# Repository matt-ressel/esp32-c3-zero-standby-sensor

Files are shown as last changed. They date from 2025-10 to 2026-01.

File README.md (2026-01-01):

# ESP32-C3 Zero-Standby Environmental Sensor

## 🎯 Project Goal

To create a wireless, battery-powered environmental sensor, optimized for extremely low power consumption. The primary goal is to achieve a theoretical battery life exceeding **10 years** on a single Li-SOCl₂ (e.g., FANSO ER18505M 3.6V, 3500mAh) battery.

This project achieves this goal through a unique **"Zero Standby"** architecture, where the microcontroller is completely disconnected from power during its idle state. The duty cycle is managed by an external, nano-power system timer.

---

## 🚀 Key Features & Architecture

*   **Ultra-Low Electronic Quiescent Current:** The total current consumed by the electronics in the power-off state has been meticulously optimized to be under 100 nA. This value is the sum of the quiescent currents (Iq) of all components permanently connected to the battery:
    *   **TPS63900 Buck-Boost (in shutdown):** ~60 nA
    *   **TPL5111 System Timer:** ~35 nA
    *   **SiP32431 Load Switch (in off-state):** ~0.01 nA (practically zero)
    *   **Total Electronic Iq ≈ 95 nA**

    This successfully achieves the design goal of making the electronic footprint in the standby state almost immeasurable. It ensures that the theoretical battery life is maximized, being limited almost exclusively by the energy consumed during the brief active cycles.
*   **Power Gating Architecture:** Instead of using Deep Sleep mode, the TPL5111 completely enables and disables the power supply for the entire system (MCU + sensor), eliminating any MCU-related leakage currents.
*   **Ultra-Fast On-Time:** The entire active cycle (boot, measure, transmit, shutdown) is highly optimized to complete in **well under 100 milliseconds** (typically ~80ms), which is critical for minimizing energy consumption.
*   **Optimized Operational Sequence:** The firmware uses advanced techniques like **latency hiding**, where long physical processes (like battery measurement stabilization) are executed in the background during other necessary initializations (like the Wi-Fi stack), effectively reducing their time cost to zero.
*   **ESP-NOW Communication:** Utilizes the lightweight and fast ESP-NOW protocol, configured for Long Range (LR) mode, for robust and low-power data transmission.
*   **Professional Component-Based Architecture:** The code is structured into fully independent, reusable components (e.g., `bme280_driver`, `espnow_sender`, `sensor_manager`) in line with the best practices for ESP-IDF, ensuring clean separation of concerns and easy maintenance.

---

## 🛠️ Hardware Components (Bill of Materials)

| Component | Model/Value | Role |
| --- | --- | --- |
| **Microcontroller** | Espressif ESP32-C3-MINI-1 | Main processing unit, RF communication |
| **System Timer** | Texas Instruments TPL5111 | External watchdog and duty cycle manager (Power Gating)  |
| **Buck-Boost Converter**| Texas Instruments TPS63900 | High-efficiency 3.3V voltage regulation |
| **Environmental Sensor**| Bosch BME280 | Measures temperature, humidity, and pressure (I²C) |
| **Battery** | FANSO ER18505M (Li-SOCl₂, 3.6V, 3500mAh) or similar | Primary power source |
| **Load Switch** | Vishay SiP32431 | Switched voltage divider for V_BATT measurement |

---

## 🔄 Optimized Software Operational Sequence

The duty cycle is fast, repeatable, and designed for maximum efficiency. The order of operations is critical.

1.  **START (Cold Boot):** The TPL5111 activates the power converter, supplying power to the system. `app_main` begins execution.

2.  **IMMEDIATE CRITICAL ACTIONS:**
    *   **Initialize Critical Drivers:** The bare minimum of drivers needed for immediate measurements are initialized (`bme280_driver`, `battery_monitor`, `power_manager`).
    *   **Start Battery Measurement:** The firmware immediately enables the external voltage divider. This starts the ~25ms physical process of charging the filter capacitor. This process now runs **in the background**.
    *   **Perform BME280 Measurement:** With the battery measurement stabilizing in the background, the CPU **immediately** performs the BME280 sensor reading. This is done as early as possible to get a temperature reading before the CPU core begins to self-heat.

3.  **LATENCY HIDING & NETWORK INIT:**
    *   While the battery measurement capacitor is charging, the firmware productively uses this time to initialize the time-consuming network stack (`wifi_service` and `espnow_sender`). This **hides the 25ms delay**, effectively making the battery stabilization time "free".

4.  **FINALIZE & TRANSMIT:**
    *   Control is passed to the `sensor_manager`.
    *   It **finalizes the battery measurement** by reading the now-stable voltage from the ADC.
    *   It assembles all data (BME280, battery) into a payload, calculates a CRC, and hands it to the `espnow_sender`.
    *   The `espnow_sender` transmits the packet and waits for a hardware-level acknowledgement (ACK) from the receiver.

5.  **SHUTDOWN:**
    *   Upon completion of the transmission (successful or not), a HIGH pulse is generated on the `DONE` pin.
    *   The TPL5111 receives the signal and immediately cuts off power to the system.
    *   A **fail-safe mechanism** is in place: if the shutdown signal fails, the MCU enters its deepest possible sleep state to conserve energy until the TPL5111's own watchdog timer performs a hard power cycle.

---

## ⚙️ Getting Started & Configuration

This project is designed for rapid setup using the provided configuration files, while still requiring user-specific network details.

### 1. Mandatory User Configuration (menuconfig)

This repository includes a pre-configured `sdkconfig` file containing all the performance optimizations listed below. This saves you the time of setting them manually.

**However, you MUST configure your own network-specific parameters before building and flashing.**

To do this, run `idf.py menuconfig` and navigate to the following menu:

`---> ESP32C3 Zero Standby Sensor Configuration`

Inside this menu, you must set the following values to match your receiver/gateway:

*   **`Gateway MAC Address`**: The MAC address of your ESP-NOW receiver.
*   **`ESPNOW primary master key (PMK)`**: A 16-character string shared with the receiver.
*   **`ESPNOW local master key (LMK)`**: A 16-character string shared with the receiver for this specific device.
*   **`ESPNOW Channel`**: The Wi-Fi channel (1-13) on which both devices will communicate.
*   **`I2C Pin Configuration`**: Specify the GPIO pins used by the I2C master for the BME280.

### 2. Summary of Key Performance Optimizations

For reference, here is a detailed list of the critical optimizations applied in the provided `sdkconfig` to achieve an ultra-fast boot time (cold boot to shutdown in < 100ms).

The following options, configured via `idf.py menuconfig`, are essential for minimizing boot time and runtime power consumption.

#### Compiler Optimization
For maximum performance, both the main application and the bootloader should be compiled with `-O2` optimization.
*   **Application Optimization Level:**
    *   `Compiler options ---> Optimization Level ---> Optimize for performance (-O2)`

*   **Bootloader Optimization Level:**
    *   `Bootloader config ---> Bootloader optimization level ---> Optimize for performance (-O2)`

#### Bootloader & Logging & System
*   **Disable Console Output (CRITICAL):** Disables the UART console driver entirely. This removes the initialization overhead of the UART peripheral and converts all logging macros to no-ops, significantly speeding up boot and execution.
    *   `Component config ---> ESP System Settings ---> Channel for console output (None)`

*   **Skip Image Validation:** This is a major optimization. It instructs the bootloader to skip the time-consuming SHA-256 validation of the application image on every boot.
    *   `Bootloader config ---> [*] Skip image validation always`

*   **Disable Bootloader Log:** Drastically speeds up the initial boot phase.
    *   `Bootloader config ---> Log ---> Bootloader log verbosity ---> No output`

*   **Disable Application Log:** Frees up CPU cycles and reduces on-time. Set to "Info" for debugging and "None" for production.
    *   `Component config ---> Log ---> Log Level ---> Default log verbosity ---> No output`

*   **FreeRTOS:** The project is configured for a single core and a 1000Hz tick rate.
    *   `Component config ---> FreeRTOS ---> Kernel ---> configTICK_RATE_HZ (1000)`

#### ADC & RTC Optimizations
*   **Place ADC ISR in IRAM:** Improves performance of ADC reads by running the code from faster RAM instead of flash.
    *   `Component config ---> ADC ---> [*] Place ISR version ADC oneshot mode read function into IRAM`

*   **Skip RTC Clock Calibration:** Reduces boot time by skipping a time-consuming calibration step.
    *   `Component config ---> Hardware Settings ---> RTC Clock Config ---> (0) Number of cycles for RTC_SLOW_CLK calibration`    

#### Wi-Fi, PHY & LWIP Stack Reduction
The goal is to strip down the network stack to the bare minimum required for ESP-NOW.
*   **Reduce Max TX Power:** A critical setting to reduce peak current draw and stay within the limits of the power supply and battery. 18dBm is a safe starting point.
    *   `Component config ---> Wi-Fi ---> (18) Max WiFi TX power (dBm)`
    
*   **Enable Brownout Power Reduction:** A fail-safe mechanism that reduces Tx power on the next boot if a brownout occurs.
    *   `Component config ---> PHY ---> [*] Reduce PHY TX power when brownout reset`

*   **Disable Unused Wi-Fi Features:** ESP-NOW does not require SoftAP, WPA3, Enterprise security, or OWE. Disabling these significantly reduces the final binary size and memory footprint.
    *   `Component config ---> Wi-Fi ---> [ ] WiFi SoftAP Support`
    *   `Component config ---> Wi-Fi ---> Security features ---> [ ] Enable WPA3-Personal`
    *   And other similar options...

*   **Disable LWIP (TCP/IP Stack):** ESP-NOW operates at the MAC layer and does not use the TCP/IP stack (LWIP). Disabling IPv6 and DHCP server further reduces code size and memory usage.
    *   `Component config ---> LWIP ---> [ ] Enable IPv6`
    *   `Component config ---> LWIP ---> [ ] DHCPS: Enable IPv4 Dynamic Host Configuration Protocol Server (DHCPS)`

#### Flash & PHY
*   **SPI Flash Configuration:** Using the fastest possible mode and frequency reduces the time spent loading the application from flash.
    *   `Serial flasher config ---> Flash SPI mode ---> QIO`
    *   `Serial flasher config ---> Flash SPI speed ---> 80 MHz`
    
*   **Disable PHY Calibration:** Skips Wi-Fi/Bluetooth PHY calibration on boot, saving a significant amount of time. This is safe as calibration data is stored in NVS and loaded on first boot.
    *   `Component config ---> PHY ---> [*] Store phy calibration data in NVS`
    *   `Component config ---> PHY ---> Calibration mode (Calibration none)`
 
### 3. Boot ROM Log Disable (eFuse) - CRITICAL STEP

By default, the ESP32-C3's internal Boot ROM prints diagnostic messages to the UART during the very first moments of startup. This adds a significant delay. Disabling this is a **one-way, irreversible operation** that requires burning eFuses.

**Warning: Burning eFuses is permanent. Proceed with caution.**

To achieve the fastest possible boot time, connect the device and run the following commands using `espefuse.py`:

```bash
# Disable ROM logs for UART0
espefuse.py --port YOUR_PORT burn_efuse UART_PRINT_CONTROL 3

# For ESP32-C3 with built-in USB-JTAG, also disable its ROM logs
espefuse.py --port YOUR_PORT burn_efuse DIS_USB_SERIAL_JTAG_ROM_PRINT 1    

```

## 📉 Real-World Performance Verification

The theoretical optimizations have been verified using a **Nordic Power Profiler Kit II (PPK2)**. The chart below captures a single, complete active cycle — from cold boot, through sensor reading and Wi-Fi initialization, to ESP-NOW transmission and final power-off.

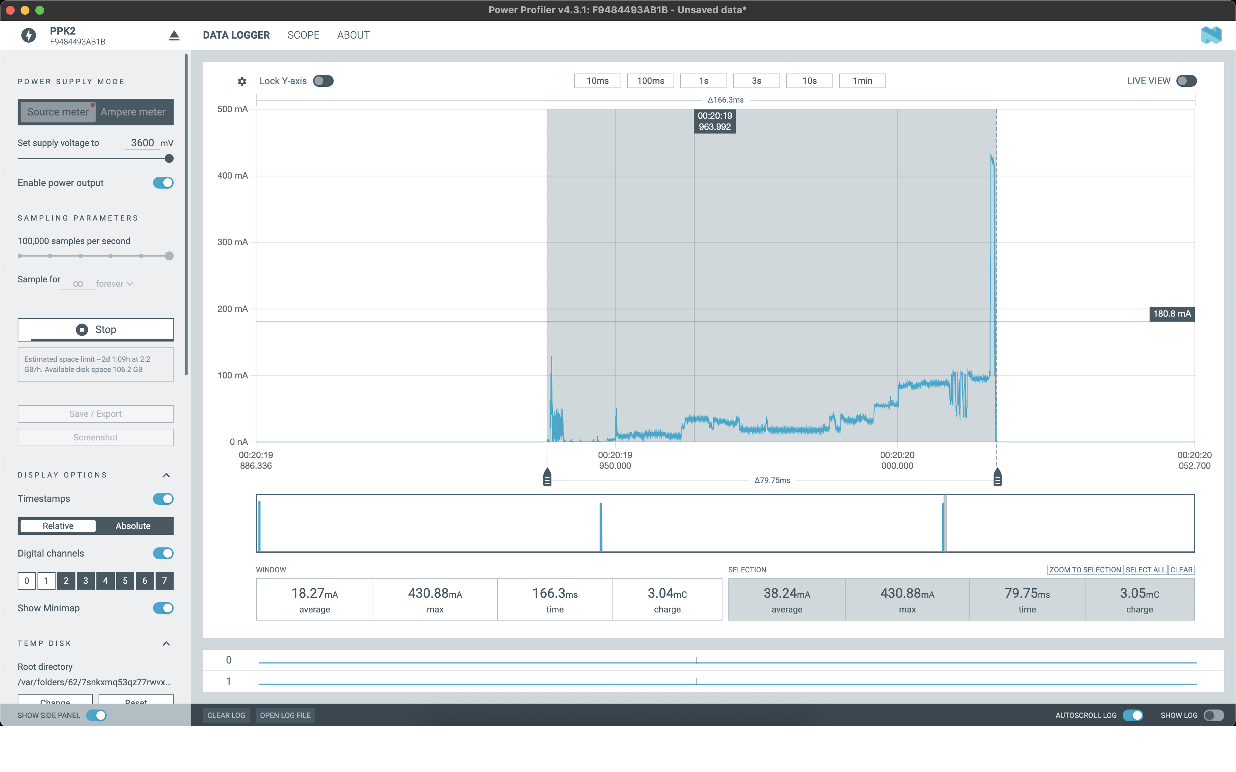
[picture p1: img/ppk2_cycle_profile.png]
PPK2 Power Profile

*(Fig. 1: Complete active cycle profile captured with PPK2 @ 3.6V)*

### Measured Metrics (per cycle):

| Metric | Measured Value | Significance |
| :--- | :--- | :--- |
| **Total On-Time** | **~80 ms** | Surpasses the goal of < 100ms. Minimizes the time the battery is under load. |
| **Total Charge** | **~3.05 mC** | Extremely low energy cost per transmission. **1 mC ≈ 0.278 µAh**, so one cycle costs just **~0.85 µAh**. |
| **Average Current** | **~38 mA** | Efficient operation during the active phase. |
| **Peak Current** | **~430 mA** | Represents the short Wi-Fi TX burst. Handled by input capacitors to protect the high-impedance battery. |

**Conclusion:** With a total charge of **3.05 mC** per cycle and a 10-minute interval, the average current consumption of the electronics is approximately **0.25 µA** (plus the ~200nA quiescent current). This confirms that the system's battery life is strictly limited by the battery's self-discharge rate, not the device's power consumption.

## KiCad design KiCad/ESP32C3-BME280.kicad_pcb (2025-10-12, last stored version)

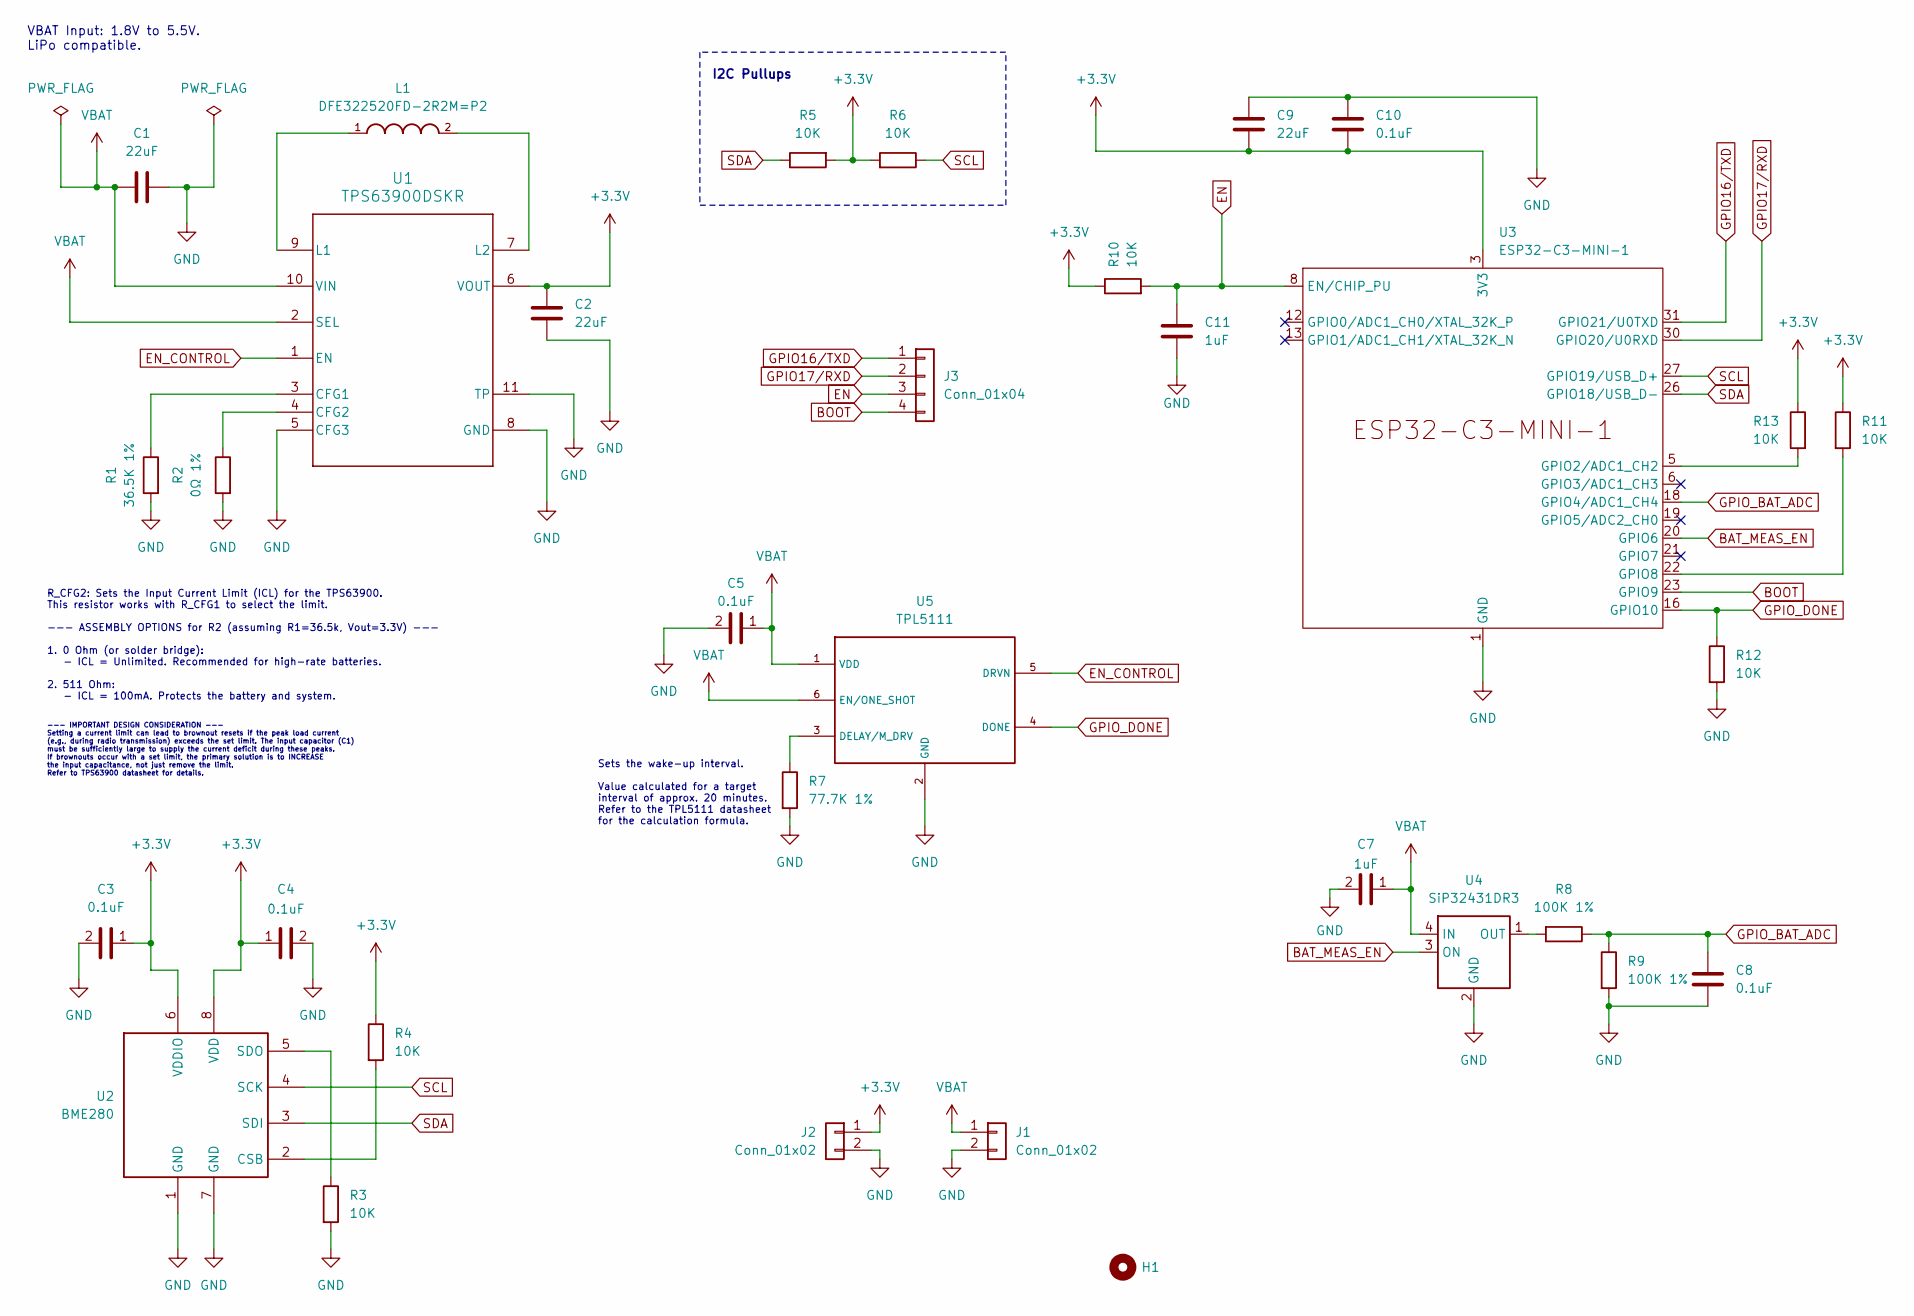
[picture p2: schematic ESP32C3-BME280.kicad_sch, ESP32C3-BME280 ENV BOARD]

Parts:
C1, C2, C9: 22uF; C_0805_2012Metric
C3, C4, C5, C8, C10: 0.1uF; C_0603_1608Metric
C7, C11: 1uF; C_0603_1608Metric
H1: MountingHole; MountingHole_2.2mm_M2_ISO7380_Pad
J1, J2: Conn_01x02; PinHeader_1x02_P2.00mm_Vertical
J3: Conn_01x04; PinHeader_1x04_P2.00mm_Vertical
L1: DFE322520FD-2R2M=P2; INDC3225X200N
R1: 36.5K 1%; R_0603_1608Metric
R2: 0Ω 1%; R_0603_1608Metric
R3, R4, R5, R6, R10, R11, R12, R13: 10K; R_0603_1608Metric
R7: 77.7K 1%; R_0603_1608Metric
R8, R9: 100K 1%; R_0603_1608Metric
U1: TPS63900DSKR; DSK0010A
U2: BME280; Bosch_LGA-8_2.5x2.5mm_P0.65mm_ClockwisePinNumbering
U3: ESP32-C3-MINI-1
U4: SiP32431DR3; SOT-363_SC-70-6
U5: TPL5111; SOT-23-6

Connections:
+3.3V: C2.1, C3.1, C4.1, C9.1, C10.1, J2.1, R4.1, R5.2, R6.2, R10.1, R11.1, R13.1, U1.6 (VOUT), U2.6 (VDDIO), U2.8 (VDD), U3.3 (3V3)
BAT_MEAS_EN: U3.20 (GPIO6), U4.3 (ON)
BOOT: J3.4, U3.23 (GPIO9)
EN: C11.1, J3.3, R10.2, U3.8 (EN/CHIP_PU)
EN_CONTROL: U1.1 (EN), U5.5 (DRVN)
GND: C1.2, C2.2, C3.2, C4.2, C5.2, C7.2, C8.2, C9.2, C10.2, C11.2, J1.2, J2.2, R1.2, R2.2, R3.2, R7.2, R9.2, R12.2, U1.5 (CFG3), U1.8 (GND), U1.11 (TP), U2.1 (GND), U2.7 (GND), U3.1 (GND), U3.2 (GND), U3.11 (GND), U3.14 (GND), U3.36 (GND), U3.37 (GND), U3.38 (GND), U3.39 (GND), U3.40 (GND), U3.41 (GND), U3.42 (GND), U3.43 (GND), U3.44 (GND), U3.45 (GND), U3.46 (GND), U3.47 (GND), U3.48 (GND), U3.49 (GND), U3.50 (GND), U3.51 (GND), U3.52 (GND), U3.53 (GND), U4.2 (GND), U4.5 (GND), U5.2 (GND)
GPIO16/TXD: J3.1, U3.31 (GPIO21/U0TXD)
GPIO17/RXD: J3.2, U3.30 (GPIO20/U0RXD)
GPIO_BAT_ADC: C8.1, R8.1, R9.1, U3.18 (GPIO4/ADC1_CH4)
GPIO_DONE: R12.1, U3.16 (GPIO10), U5.4 (DONE)
unnamed: R1.1, U1.3 (CFG1)
unnamed: R2.1, U1.4 (CFG2)
unnamed: L1.1, U1.9 (L1)
unnamed: L1.2, U1.7 (L2)
unnamed: R4.2, U2.2 (CSB)
unnamed: R3.1, U2.5 (SDO)
unnamed: R13.2, U3.5 (GPIO2/ADC1_CH2)
unnamed: R11.2, U3.22 (GPIO8)
unnamed: R8.2, U4.1 (OUT)
unnamed: R7.1, U5.3 (DELAY/M_DRV)
SCL: R6.1, U2.4 (SCK), U3.27 (GPIO19/USB_D+)
SDA: R5.1, U2.3 (SDI), U3.26 (GPIO18/USB_D-)
VBAT: C1.1, C5.1, C7.1, J1.1, U1.2 (SEL), U1.10 (VIN), U4.4 (IN), U5.1 (VDD), U5.6 (EN/ONE_SHOT)

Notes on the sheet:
Sets the wake-up interval. Value calculated for a target interval of approx. 20 minutes. Refer to the TPL5111 datasheet for the calculation formula.
R_CFG2: Sets the Input Current Limit (ICL) for the TPS63900. This resistor works with R_CFG1 to select the limit. --- ASSEMBLY OPTIONS for R2 (assuming R1=36.5k, Vout=3.3V) --- 1. 0 Ohm (or solder bridge): - ICL = Unlimited. Recommended for high-rate batteries. 2. 511 Ohm: - ICL = 100mA. Protects t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
I2C Pullups
--- IMPORTANT DESIGN CONSIDERATION --- Setting a current limit can lead to brownout resets if the peak load current (e.g., during radio transmission) exceeds the set limit. The input capacitor (C1) must be sufficiently large to supply the current deficit during these peaks. If brownouts occur with 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
VBAT Input: 1.8V to 5.5V. LiPo compatible.

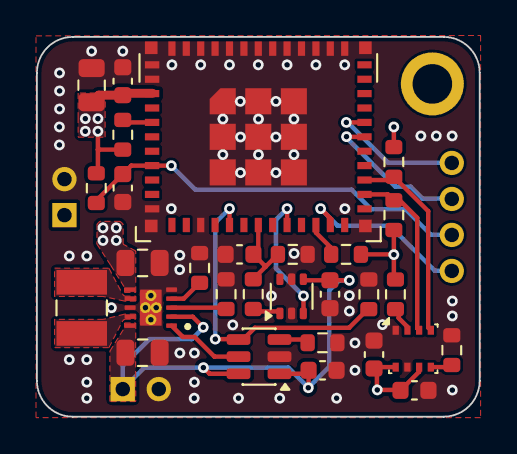
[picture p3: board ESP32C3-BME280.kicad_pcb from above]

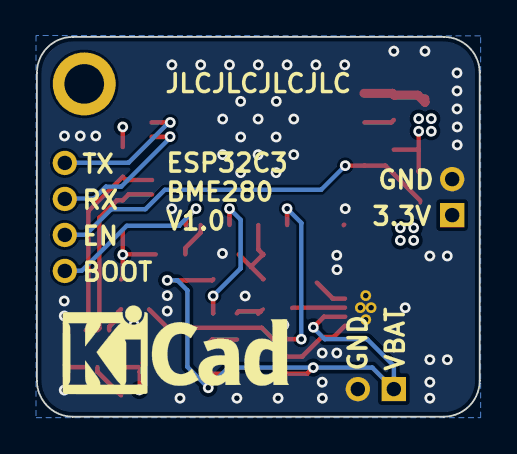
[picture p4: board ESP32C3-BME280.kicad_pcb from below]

Board: 4 copper layers, 24.6 x 21.1 mm, 33 parts (3 on the bottom side), 23 nets.

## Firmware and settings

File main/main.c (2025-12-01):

/**
 * @file main.c
 * @author Mateusz Ressel (https://github.com/matt-ressel)
 *
 * @brief Main application entry point for the ESP32-C3 Zero Standby Sensor.
 *
 * This file contains the `app_main` function, which serves as the top-level
 * orchestrator for the sensor's lifecycle. Its primary role is to initialize
 * all system services and components in a highly optimized order, execute the
 * main operational cycle by invoking the appropriate managers, and finally,
 * trigger the system power-down.
 *
 * @version 1.0
 * @date    2025-11-09
 *
 * @copyright Copyright (c) 2025 Mateusz Ressel. Licensed under the MIT License.
 *
 */

// ESP-IDF includes
#include "esp_err.h"    // For ESP_OK and other standard error codes from ESP-IDF
#include "esp_log.h"    // For ESP-IDF logging utilities (ESP_LOGI, ESP_LOGW, ESP_LOGE)
#include "esp_sleep.h"  // For deep sleep functions and types
#include "nvs_flash.h"  // For Non-Volatile Storage, a prerequisite for the WiFi stack

// Project specific module includes
#include "battery_monitor.h"  // For measuring battery voltage
#include "bme280_driver.h"    // For acquiring environmental data
#include "espnow_sender.h"    // For ESP-NOW data transmission
#include "power_manager.h"    // For controlling the shutdown signal to the TPL5111
#include "sensor_manager.h"   // For orchestrating the sensor operations
#include "wifi_service.h"     // For WiFi stack initialization (prerequisite for ESP-NOW)

/** @brief Logging tag specifically for messages originating from this main application file. */
static const char* TAG_MAIN_APP = "MAIN_APP";

/**
 * @brief Main application entry point and orchestrator of the sensor's operational sequence.
 *
 * The sequence of operations in this function is critically optimized to achieve
 * two primary goals:
 * 1. To perform the temperature-sensitive BME280 measurement as early as possible
 *    after power-on, minimizing the impact of CPU self-heating.
 * 2. To hide the latency of physical processes (like capacitor charging for the
 *    battery measurement) behind other necessary, long-running initializations
 *    (like the Wi-Fi stack).
 *
 * @par Phase 1: Prerequisites and Critical Driver Initialization
 * Initializes NVS (a mandatory prerequisite for Wi-Fi) and the core hardware
 * drivers that need to be ready for immediate action.
 *
 * @par Phase 2: Optimized, Time-Sensitive Operations
 * This is the most time-critical section. It starts the physical battery
 * measurement process (which requires a ~25ms stabilization delay) and then
 * *immediately* performs the BME280 digital measurement. This ensures the
 * temperature reading is captured before the CPU has a chance to significantly heat up.
 *
 * @par Phase 3: Non-Critical Initializations
 * While the filter capacitor for the battery measurement is physically stabilizing,
 * the CPU is productively used to initialize the time-consuming network stack
 * (Wi-Fi and ESP-NOW). This effectively "hides" the 25ms battery delay,
 * reducing the total system "on-time".
 *
 * @par Phase 4: Main Logic Execution
 * Control is passed to the `sensor_manager`. It receives the pre-measured BME280
 * data and is responsible for the rest of the business logic: finalizing the
 * battery measurement, assembling the data payload, and transmitting it.
 *
 * @par Phase 5: System Shutdown
 * The final step is to signal the external timer via the `power_manager` to cut
 * system power. A fail-safe mechanism (deep sleep) is included in the unlikely
 * event that the shutdown signal fails.
 *
 * @note Note how `main.c` acts as a high-level "CEO", managing the *lifecycle*
 *       and *sequence*, while the `sensor_manager` acts as a "Manager", handling
 *       the *business logic* of processing and sending data. This separation of
 *       concerns is a key architectural feature of this project.
 */

void app_main(void) {
  bme280_data_t sensor_data;  // Structure to hold BME280 measurement data

  ESP_LOGI(TAG_MAIN_APP, "--- ESP32-C3 Zero Standby Sensor: Cold Boot ---");

  // --- System Prerequisites Initialization ---
  // --- Phase 1: Prerequisites and Critical Driver Initialization ---
  ESP_LOGI(TAG_MAIN_APP, "Initializing prerequisites and critical drivers...");
  esp_err_t ret = nvs_flash_init();
  if (ret == ESP_ERR_NVS_NO_FREE_PAGES || ret == ESP_ERR_NVS_NEW_VERSION_FOUND) {
    ESP_ERROR_CHECK(nvs_flash_erase());
    ret = nvs_flash_init();
  }
  ESP_ERROR_CHECK(ret);

  ESP_ERROR_CHECK_WITHOUT_ABORT(power_manager_init());    // Initialize power manager
  ESP_ERROR_CHECK_WITHOUT_ABORT(bme280_driver_init());    // Initialize BME280 driver
  ESP_ERROR_CHECK_WITHOUT_ABORT(battery_monitor_init());  // Initialize battery monitor

  // --- Phase 2: Optimized, Time-Sensitive Operations --
  ESP_LOGI(TAG_MAIN_APP, "Starting latency-hiding and time-critical measurements...");
  // Start the physical process of battery measurement (capacitor charging).
  // The ~25ms stabilization time will now pass in the background.
  ESP_ERROR_CHECK_WITHOUT_ABORT(battery_monitor_start_measurement());

  // Immediately perform the BME280 measurement to get the purest temperature reading
  ESP_LOGI(TAG_MAIN_APP, "Performing immediate BME280 measurement...");
  ESP_ERROR_CHECK_WITHOUT_ABORT(bme280_driver_read_data(&sensor_data));

  // --- Phase 3: Non-Critical Initializations ---
  ESP_LOGI(TAG_MAIN_APP, "Initializing network stack (hiding battery measurement latency)...");
  ESP_ERROR_CHECK_WITHOUT_ABORT(wifi_service_init());
  ESP_ERROR_CHECK_WITHOUT_ABORT(espnow_sender_init());

  // --- Phase 4: Main Logic Execution ---
  ESP_LOGI(TAG_MAIN_APP, "All initializations complete. Running the sensor manager...");
  ESP_ERROR_CHECK_WITHOUT_ABORT(sensor_manager_run(&sensor_data));

  // --- Phase 5: System Shutdown ---
  ESP_LOGI(TAG_MAIN_APP, "Signaling shutdown...");
  // Signal the TPL5111 to cut power. This is the final action.
  power_manager_shutdown();

  // --- Fail-safe: This code should be unreachable ---
  // If we are here, it means the primary shutdown signal to the TPL5111 failed.
  // As a last resort, we enter deep sleep to minimize power consumption.
  ESP_LOGE(TAG_MAIN_APP, "CRITICAL: Shutdown signal failed! Entering deep sleep as a fail-safe.");
  // Disable all wake-up sources to ensure the device stays in deep sleep
  esp_sleep_disable_wakeup_source(ESP_SLEEP_WAKEUP_ALL);

  // We do not configure a wake-up timer. The external TPL5111 will perform a
  // hard power-cycle after its ~20 minute interval, which will restart the system.
  // This call puts the device into the lowest possible power state indefinitely.
  esp_deep_sleep_start();
}

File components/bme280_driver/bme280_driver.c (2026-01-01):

/**
 * @file bme280_driver.c
 * @author Mateusz Ressel (https://github.com/matt-ressel)
 *
 * @brief Implementation of the minimal, custom BME280 sensor driver.
 *
 * This file contains the logic for direct I2C communication with the BME280,
 * readout of calibration data, and application of the compensation formulas
 * as specified in the Bosch BME280 datasheet.
 * It uses the modern, handle-based ESP-IDF I2C master driver from 'driver/i2c_master.h'.
 *
 * @version 0.2
 * @date    2025-11-15
 *
 * @copyright Copyright (c) 2025 Mateusz Ressel. Licensed under the MIT License.
 *
 */

#include "bme280_driver.h"  // Include the corresponding header file

// ESP-IDF includes
#include "driver/i2c_master.h"
#include "esp_log.h"
// #include "esp_rom_sys.h"

// FreeRTOS includes
#include "freertos/FreeRTOS.h"
#include "freertos/task.h"

// --- Hardware Specific Configuration ---
#define I2C_MASTER_NUM I2C_NUM_0    /*!< I2C port number for master dev */
#define I2C_MASTER_TX_BUF_DISABLE 0 /*!< I2C master doesn't need buffer */
#define I2C_MASTER_RX_BUF_DISABLE 0 /*!< I2C master doesn't need buffer */
#define I2C_TIMEOUT_MS 100          /*!< I2C operation timeout in milliseconds */

// --- BME280 Register Addresses (from datasheet, chapter 5) ---

#define BME280_SENSOR_ADDR 0x76     // BME280 I2C address (0x77 if SDO is high)
#define BME280_REG_ID 0xD0          // Chip ID register
#define BME280_REG_CALIB_00 0x88    // Start of first calibration data block
#define BME280_REG_CALIB_26 0xE1    // Start of second calibration data block
#define BME280_REG_CTRL_HUM 0xF2    // Humidity control register
#define BME280_REG_CTRL_MEAS 0xF4   // Measurement control register
#define BME280_REG_DATA_START 0xF7  // Start of data registers (press, temp, hum)

// Logging tag for this module
static const char* TAG = "BME280_DRIVER";

// --- Static Handles for I2C Communication ---
static i2c_master_bus_handle_t s_i2c_bus_handle;
static i2c_master_dev_handle_t s_bme280_dev_handle;

/** @brief Flag indicating if the BME280 driver has been initialized. */
static bool s_is_initialized = false;

/**
 * @brief Structure to hold all factory calibration coefficients.
 * @note The data types match those specified in the BME280 datasheet, table 16.
 */
typedef struct {
  // Temperature calibration coefficients
  uint16_t dig_T1;
  int16_t dig_T2;
  int16_t dig_T3;

  // Pressure calibration coefficients
  uint16_t dig_P1;
  int16_t dig_P2;
  int16_t dig_P3;
  int16_t dig_P4;
  int16_t dig_P5;
  int16_t dig_P6;
  int16_t dig_P7;
  int16_t dig_P8;
  int16_t dig_P9;

  // Humidity calibration coefficients
  uint8_t dig_H1;
  int16_t dig_H2;
  uint8_t dig_H3;
  int16_t dig_H4;
  int16_t dig_H5;
  int8_t dig_H6;
} bme280_calib_data_t;

/** @brief Static instance of calibration data, read once during initialization. */
static bme280_calib_data_t s_calib_data;
/** @brief Fine-resolution temperature value, used for P and H compensation. */
static int32_t t_fine;

// --- Private I2C Helper Functions ---

/** @brief Reads a sequence of bytes from a BME280 register using the new driver API. */
static esp_err_t bme280_i2c_read_reg(uint8_t reg_addr, uint8_t* data, size_t len) {
  return i2c_master_transmit_receive(s_bme280_dev_handle, &reg_addr, 1, data, len, I2C_TIMEOUT_MS);
}

/** @brief Writes a single byte to a BME280 register using the new driver API. */
static esp_err_t bme280_i2c_write_reg(uint8_t reg_addr, uint8_t data) {
  uint8_t write_buf[2] = {reg_addr, data};
  return i2c_master_transmit(s_bme280_dev_handle, write_buf, sizeof(write_buf), I2C_TIMEOUT_MS);
}

// --- Compensation Formulas (from BME280 datasheet, section 4.2.3) ---

/** @brief Compensates the raw temperature reading and sets the global t_fine. */
static int32_t compensate_temperature(int32_t adc_T) {
  int32_t var1 = ((((adc_T >> 3) - ((int32_t)s_calib_data.dig_T1 << 1))) * ((int32_t)s_calib_data.dig_T2)) >> 11;
  int32_t var2 = (((((adc_T >> 4) - ((int32_t)s_calib_data.dig_T1)) * ((adc_T >> 4) - ((int32_t)s_calib_data.dig_T1))) >> 12) * ((int32_t)s_calib_data.dig_T3)) >> 14;
  t_fine = var1 + var2;
  return (t_fine * 5 + 128) >> 8;  // Returns temp in DegC * 100
}

/** @brief Compensates the raw pressure reading using t_fine. */
static uint32_t compensate_pressure(int32_t adc_P) {
  int64_t var1, var2, p;
  var1 = ((int64_t)t_fine) - 128000;
  var2 = var1 * var1 * (int64_t)s_calib_data.dig_P6;
  var2 += ((var1 * (int64_t)s_calib_data.dig_P5) << 17);
  var2 += (((int64_t)s_calib_data.dig_P4) << 35);
  var1 = ((var1 * var1 * (int64_t)s_calib_data.dig_P3) >> 8) + ((var1 * (int64_t)s_calib_data.dig_P2) << 12);
  var1 = (((((int64_t)1) << 47) + var1)) * ((int64_t)s_calib_data.dig_P1) >> 33;
  if (var1 == 0) return 0;  // Avoid division by zero
  p = 1048576 - adc_P;
  p = (((p << 31) - var2) * 3125) / var1;
  var1 = (((int64_t)s_calib_data.dig_P9) * (p >> 13) * (p >> 13)) >> 25;
  var2 = (((int64_t)s_calib_data.dig_P8) * p) >> 19;
  p = ((p + var1 + var2) >> 8) + (((int64_t)s_calib_data.dig_P7) << 4);
  return (uint32_t)p;  // Returns pressure in Pascals (Pa)
}

/** @brief Compensates the raw humidity reading using t_fine. */
static uint32_t compensate_humidity(int32_t adc_H) {
  int32_t v_x1_u32r = (t_fine - 76800);
  v_x1_u32r = (((((adc_H << 14) - (((int32_t)s_calib_data.dig_H4) << 20) - (((int32_t)s_calib_data.dig_H5) * v_x1_u32r)) + 16384) >> 15) *
               (((((((v_x1_u32r * ((int32_t)s_calib_data.dig_H6)) >> 10) * (((v_x1_u32r * ((int32_t)s_calib_data.dig_H3)) >> 11) + 32768)) >> 10) + 2097152) *
                     ((int32_t)s_calib_data.dig_H2) +
                 8192) >>
                14));
  v_x1_u32r = (v_x1_u32r - (((((v_x1_u32r >> 15) * (v_x1_u32r >> 15)) >> 7) * ((int32_t)s_calib_data.dig_H1)) >> 4));
  v_x1_u32r = (v_x1_u32r < 0 ? 0 : v_x1_u32r);
  v_x1_u32r = (v_x1_u32r > 419430400 ? 419430400 : v_x1_u32r);
  return (uint32_t)(v_x1_u32r >> 12);  // Returns humidity in %RH * 1024
}

// --- Public API Function Implementations ---
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

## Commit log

2025-10-12 Add KiCad files
    [ESP32C3-BME280.kicad_pcb, ESP32C3-BME280.kicad_sch]
2025-10-20 Add I2C configuration options: Introduce I2C SDA pin, SCL pin, and master frequency settings in Kconfig.projbuild
2025-10-20 Add shared component CMakeLists.txt and sensor_data.h: Define structure for sensor readings with detailed documentation
2025-10-20 Add BME280 driver implementation: Introduce bme280_driver.c and bme280_driver.h for sensor communication and data handling
2025-10-20 Refactor logging tag comment in BME280 driver for clarity
2025-10-20 Add sensor manager component: Implement sensor_manager.c and sensor_manager.h for data acquisition, processing, and transmission
2025-10-28 Add Battery Monitor and Power Manager components: Implement CMakeLists.txt, source, and header files for battery monitoring and power management functionalities
2025-10-28 Refactor main.c: Enhance documentation, optimize initialization phases, and improve logging for sensor lifecycle management
2025-11-16 Add battery monitor component: Implement source and header files for battery voltage measurement, including initialization, measurement, and de-initialization functions.
2025-11-16 Add Power Manager component: Implement source and header files for power management, including initialization, de-initialization, and shutdown functionalities.
2025-11-16 Update BME280 driver: Increment version to 0.2, enhance initialization checks, and improve logging for data readings
2025-11-16 Update sensor manager: Increment version to 0.2, enhance BME280 data processing, and improve battery measurement handling.
2025-11-16 Update main application: Increment version to 1.0, refactor initialization error handling, and improve logging for BME280 measurements.
    [main.c]
2025-12-01 Fix logging statement in app_main to ensure proper initialization message is logged
    [main.c]
2025-12-20 Update README.md: Clarify electronic quiescent current terminology and enhance project setup instructions
2026-01-01 Update BME280 driver: Correct pressure value comment to reflect Q24.8 format
    [bme280_driver.c]
2026-01-01 Fix temperature calculation in sensor_manager_run function
2026-01-01 Update sdkconfig: Disable default console UART and set UART parameters to -1
